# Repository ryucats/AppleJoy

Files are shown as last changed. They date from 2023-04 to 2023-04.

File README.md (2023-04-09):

# AppleJoy
Adapter for Atari/Sega joysticks on Apple ][ / Franklin ACE 1000

This is a slight reworking of Tor Arne Hustvedt's "Apple IIe digital joystick adaptor for using Kempston/Atari/Amiga digital joysticks on an Apple IIe", available at https://www.pcbway.com/project/shareproject/Apple_IIe_digital_joystick_adaptor_for_using_Kempston_SEGA_Atari_Amiga_digital_joysticks_on_an_Apple_IIe.html

The schematic has been recreated from the board file, and the BC558 PNP transistors have been replaced with 2N3906 transistors (which seem to be more readily available).

STL files for a 3d-printed case are in the stl/ directory.

The resulting board works perfectly on a Franklin ACE 1000 using an Apple //e-to-][+ game port adapter purchased from console5 (https://console5.com/store/byteboosters-9-pin-to-dip-16-pin-joystick-adapter-for-apple-ii-plus.html).  As it appears to be out of stock, I'll trace out the connections at some point and publish a DIY clone.

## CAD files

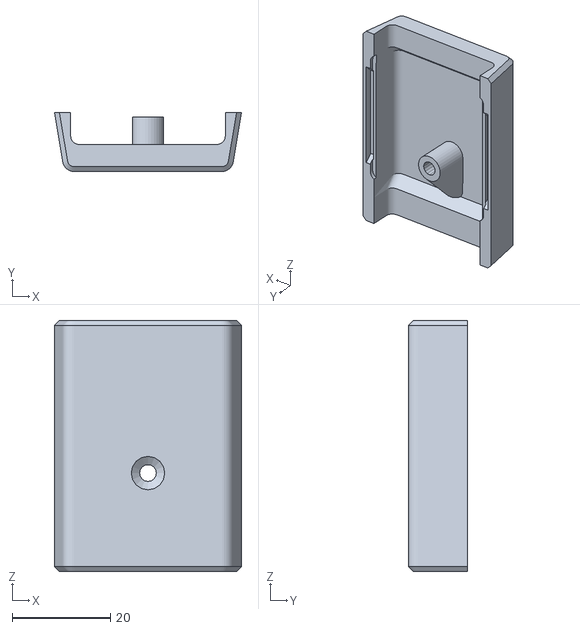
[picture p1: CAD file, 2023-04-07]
stl/Joyadapter02.STL
38.0 x 12.0 x 51.0

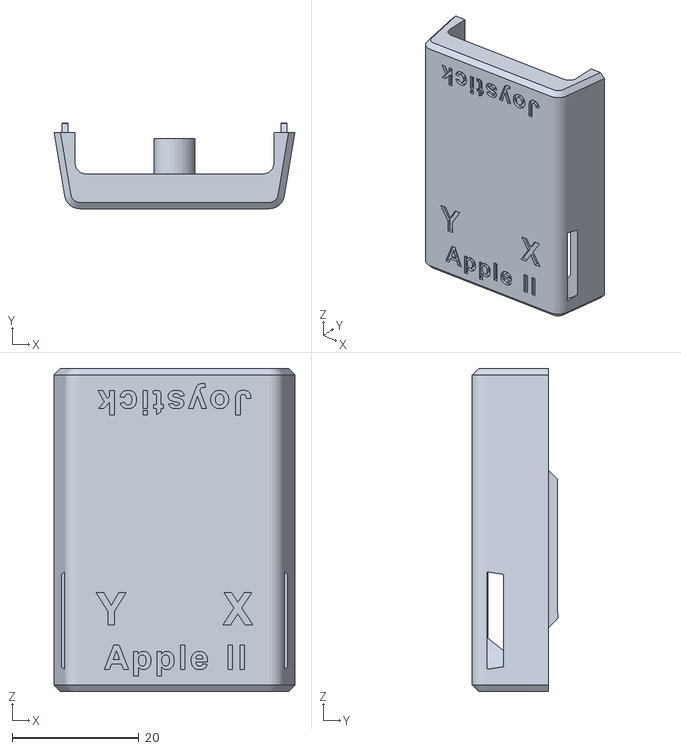
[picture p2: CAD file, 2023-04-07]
stl/Joyadapter01.STL
38.0 x 13.5 x 51.0

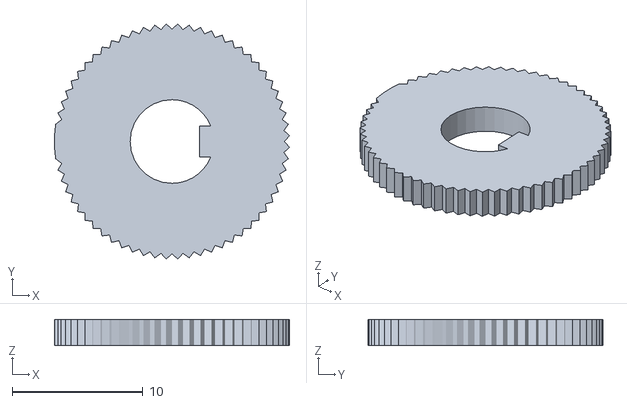
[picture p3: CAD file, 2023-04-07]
stl/Joyadapter03.STL
18.0 x 18.0 x 2.00

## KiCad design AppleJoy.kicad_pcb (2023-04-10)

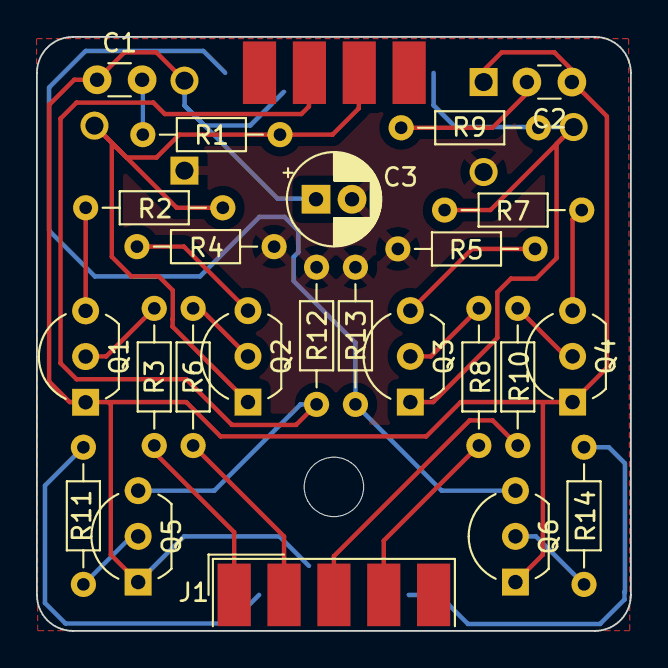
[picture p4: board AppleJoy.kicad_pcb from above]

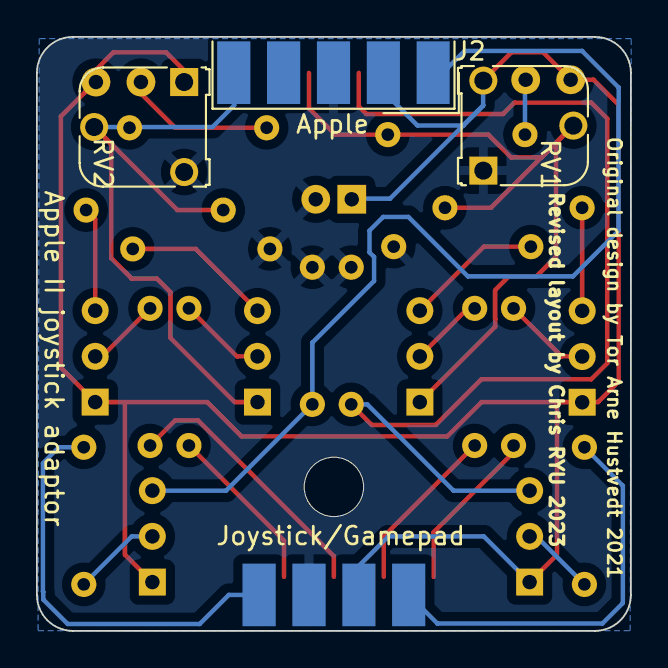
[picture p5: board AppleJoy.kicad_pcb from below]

Board: 2 copper layers, 33.0 x 33.0 mm, 27 parts (3 on the bottom side), 24 nets.

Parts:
C1, C2: C_Small; C_Disc_D3.0mm_W1.6mm_P2.50mm
C3: 1uF; CP_Radial_D5.0mm_P2.00mm
J1: Atari; DSUB-9_Male_EdgeMount_P2.77mm
J2: Apple; DSUB-9_Male_EdgeMount_P2.77mm
Q1, Q2, Q3, Q4, Q5, Q6: BC558; TO-92_Inline_Wide
R1, R2, R3, R6, R7, R8, R9, R10, R11, R14: 1k; R_Axial_DIN0204_L3.6mm_D1.6mm_P7.62mm_Horizontal
R4, R5: 10k; R_Axial_DIN0204_L3.6mm_D1.6mm_P7.62mm_Horizontal
R12, R13: 560; R_Axial_DIN0204_L3.6mm_D1.6mm_P7.62mm_Horizontal
RV1, RV2: 100k; Potentiometer_Runtron_RM-065_Vertical

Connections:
+5V: C1.1, C2.1, C3.1, J1.7, J2.2, Q1.1 (E), Q4.1 (E), Q5.1 (E), Q6.1 (E), RV1.3, RV2.1
BUT_0: J2.7, Q5.3 (C), R12.2
BUT_1: J2.1, Q6.3 (C), R13.2
DOWN: J1.2, R6.2
GAME0: J2.5, Q3.1 (E), R7.1, R9.2, RV2.2
GAME1: J2.8, Q2.1 (E), R1.2, R2.1, RV1.2
GND: C3.2, J1.8, J2.3, R4.1, R5.1, R12.1, R13.1, RV1.1, RV2.3
LEFT: J1.3, R10.2
unnamed: C1.2, R1.1
unnamed: C2.2, R9.1
unnamed: Q1.2 (B), R3.1
unnamed: Q1.3 (C), R2.2
unnamed: Q2.2 (B), R6.1
unnamed: Q2.3 (C), R4.2
unnamed: Q3.2 (B), R8.1
unnamed: Q3.3 (C), R5.2
unnamed: Q4.2 (B), R10.1
unnamed: Q4.3 (C), R7.2
unnamed: Q5.2 (B), R11.1
unnamed: Q6.2 (B), R14.1
PADDLE_A: J1.9, R14.2
RIGHT: J1.4, R8.2
TRIGGER: J1.6, R11.2
UP: J1.1, R3.2

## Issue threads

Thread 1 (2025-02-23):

original pcb, test on Apple II GS

pasmoi87, 2025-02-23:
Hi,

I just tested the adapter on my Apple II GS and I have a little problem.
Is it the fact that this is a GS???
So I test with the small BASIC program which displays the values   of PDL(0) and PDL(1) to adjust the resistors and I test the joystick (joystick ok with an LED tester). No problem on Y with up and down showing 2-4 and 252-254 or vice versa. On the other hand on X the left poses a problem the value is good 2-4 but puts the Y at 10-126 at the same time, no problem on the right with 252-254.
Any idea of   the problem? Same problem with 100pF or 10pF.

THANKS.

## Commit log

2023-04-07 Add note about STL files.
2023-04-07 Add the KiCAD files.
    [AppleJoy.kicad_pcb, AppleJoy.kicad_sch, Joyadapter01.STL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]
2023-04-10 Slight tweaks for PCBway.
    [AppleJoy.kicad_pcb]
